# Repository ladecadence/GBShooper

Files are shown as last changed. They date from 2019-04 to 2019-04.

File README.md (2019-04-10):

# GBShooper

Open source hardware GameBoy™ FlashCart Reader/Programmer

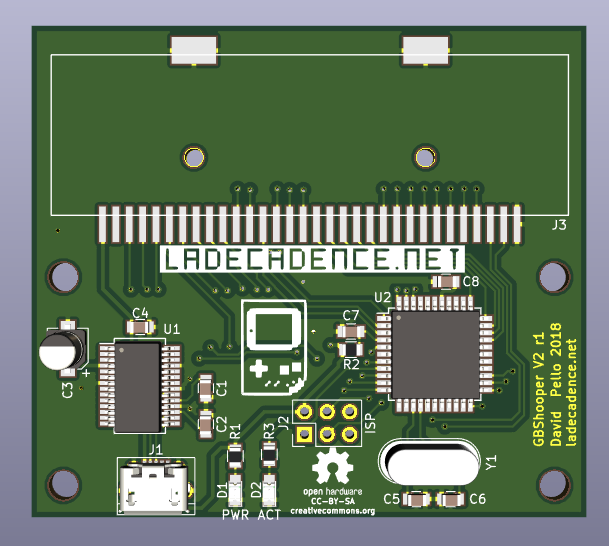
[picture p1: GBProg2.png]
GBShooper PCB


This flashcart programmer, uses the firmware at (https://github.com/ladecadence/GBShooper-Firmware)

For building it, you'll need an Atmega8515L-16AI (TQFP, -8AI also ok), a ft232rl (soic28), a 6MHz xtal, and some passives, like capacitors, resistors and LEDs.

Full Bill of Materials in the BOM file (LibreOffice and PDF).

You'll also need a micro-usb "B" connector, and a GameBoy Cartridge connector. This version uses SMD replacement connectors for the Nintendo DS, you can find them online in Aliexpress or the like.

You can use this programmer to dump original cartridges, and flash DIY flashcarts and some other flashcarts based on DIY designs and nintendo mappers (or clones).
PC-Side software is being developed right now and will also be published at ladecadence.net github.

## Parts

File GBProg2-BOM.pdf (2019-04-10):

GBProg2

Página 1

Id Identificador | Empaquetado | Cantidad Identificación | Suministrador y ref
1 J3 | GB-Cart-NDS-Aliexpress | 1 GB-CART
2 J2 | Pin_Header_Straight_2x03_Pitch2.54mm | 1 ISP
3 J1 | USB_Micro-B | 1 USB_OTG
4 Y1 | Crystal_HC49-4H_Vertical | 1 3.6864MHz
5 C1,C4,C7,C8,C2 | C_0805 | 5 100n
6 C5,C6 | C_0805 | 2 22p
7 D1 | LED_0805 | 1 PWR | Green
8 D2 | LED_0805 | 1 ACT | Red
9 R1,R3 | R_0805 | 2 220
10 R2 | R_0805 | 1 10K
11 U2 | TQFP-44_10x10mm_Pitch0.8mm | 1 ATMEGA8515-16AU | -8AU Also OK
12 C3 | CP_Elec_4x5.3 | 1 4,7u
13 U1 | SSOP-28_5.3x10.2mm_Pitch0.65mm | 1 FT232R

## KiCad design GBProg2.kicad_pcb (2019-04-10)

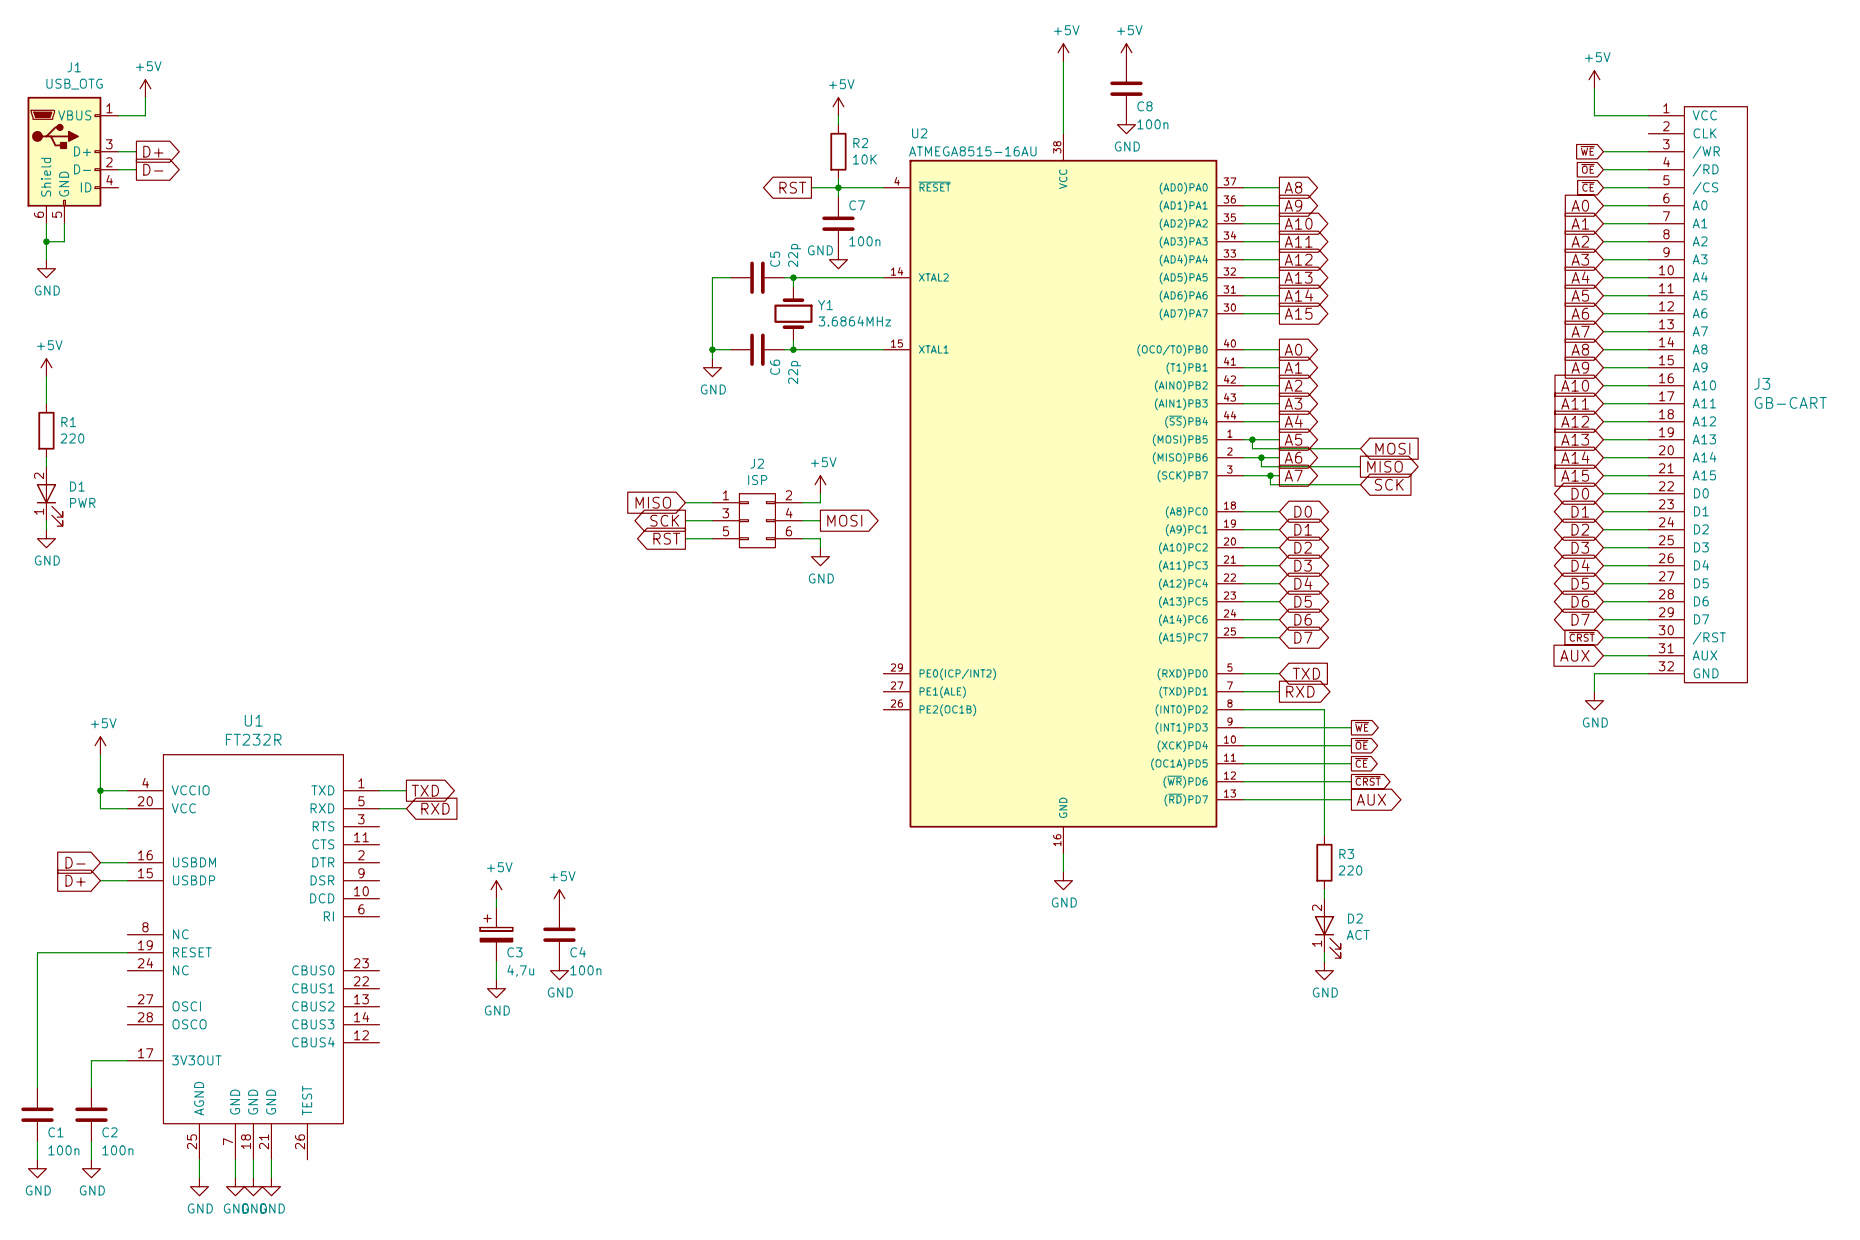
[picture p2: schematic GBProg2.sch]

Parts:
C1, C2, C4, C7, C8: 100n; C_0805
C3: 4,7u; CP_Elec_4x5.3
C5, C6: 22p; C_0805
D1: PWR; LED_0805
D2: ACT; LED_0805
J1: USB_OTG; USB_Micro-B
J2: ISP; Pin_Header_Straight_2x03_Pitch2.54mm
J3: GB-CART; GB-Cart-NDS-Aliexpress
R1, R3: 220; R_0805
R2: 10K; R_0805
U1: FT232R; SSOP-28_5.3x10.2mm_Pitch0.65mm
U2: ATMEGA8515-16AU; TQFP-44_10x10mm_Pitch0.8mm
Y1: 3.6864MHz; Crystal_HC49-4H_Vertical

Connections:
+5V: C3.1, C4.1, C8.1, J1.1 (VBUS), J2.2, J3.1 (VCC), R1.1, R2.1, U1.4 (VCCIO), U1.20 (VCC), U2.38 (VCC)
A0: J3.6 (A0), U2.40 ((OC0/T0)PB0)
A1: J3.7 (A1), U2.41 ((T1)PB1)
A2: J3.8 (A2), U2.42 ((AIN0)PB2)
A3: J3.9 (A3), U2.43 ((AIN1)PB3)
A4: J3.10 (A4), U2.44 ((~SS~)PB4)
A5: J2.4, J3.11 (A5), U2.1 ((MOSI)PB5)
A6: J2.1, J3.12 (A6), U2.2 ((MISO)PB6)
A7: J2.3, J3.13 (A7), U2.3 ((SCK)PB7)
A8: J3.14 (A8), U2.37 ((AD0)PA0)
A9: J3.15 (A9), U2.36 ((AD1)PA1)
A10: J3.16 (A10), U2.35 ((AD2)PA2)
A11: J3.17 (A11), U2.34 ((AD3)PA3)
A12: J3.18 (A12), U2.33 ((AD4)PA4)
A13: J3.19 (A13), U2.32 ((AD5)PA5)
A14: J3.20 (A14), U2.31 ((AD6)PA6)
A15: J3.21 (A15), U2.30 ((AD7)PA7)
AUX: J3.31 (AUX), U2.13 ((~RD~)PD7)
D0: J3.22 (D0), U2.18 ((A8)PC0)
D1: J3.23 (D1), U2.19 ((A9)PC1)
D2: J3.24 (D2), U2.20 ((A10)PC2)
D3: J3.25 (D3), U2.21 ((A11)PC3)
D4: J3.26 (D4), U2.22 ((A12)PC4)
D5: J3.27 (D5), U2.23 ((A13)PC5)
D6: J3.28 (D6), U2.24 ((A14)PC6)
D7: J3.29 (D7), U2.25 ((A15)PC7)
D+: J1.3 (D+), U1.15 (USBDP)
D-: J1.2 (D-), U1.16 (USBDM)
GND: C1.2, C2.2, C3.2, C4.2, C5.1, C6.1, C7.2, C8.2, D1.1 (K), D2.1 (K), J1.5 (GND), J1.6 (Shield), J2.6, J3.32 (GND), U1.7 (GND), U1.18 (GND), U1.21 (GND), U1.25 (AGND), U2.16 (GND)
unnamed: C1.1, U1.19 (RESET)
unnamed: C2.1, U1.17 (3V3OUT)
unnamed: C5.2, U2.14 (XTAL2), Y1.1
unnamed: C6.2, U2.15 (XTAL1), Y1.2
unnamed: D1.2 (A), R1.2
unnamed: D2.2 (A), R3.2
unnamed: R3.1, U2.8 ((INT0)PD2)
RST: C7.1, J2.5, R2.2, U2.4 (~RESET)
RXD: U1.5 (RXD), U2.7 ((TXD)PD1)
TXD: U1.1 (TXD), U2.5 ((RXD)PD0)
~CE: J3.5 (/CS), U2.11 ((OC1A)PD5)
~CRST: J3.30 (/RST), U2.12 ((~WR~)PD6)
~OE: J3.4 (/RD), U2.10 ((XCK)PD4)
~WE: J3.3 (/WR), U2.9 ((INT1)PD3)

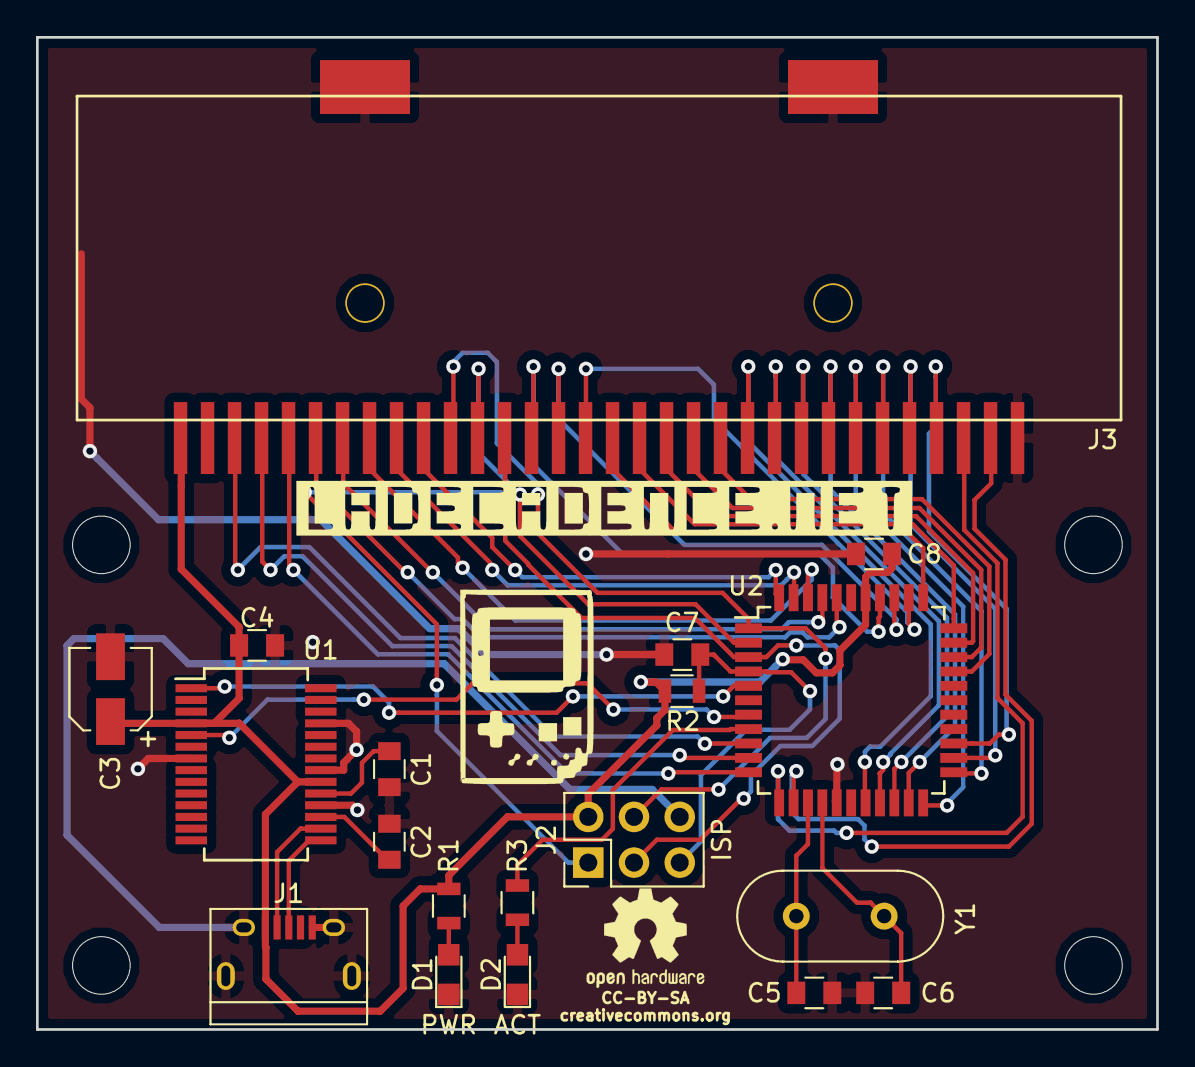
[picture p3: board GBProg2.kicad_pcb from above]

Board: 2 copper layers, 62.2 x 55.1 mm, 19 parts (0 on the bottom side), 43 nets.

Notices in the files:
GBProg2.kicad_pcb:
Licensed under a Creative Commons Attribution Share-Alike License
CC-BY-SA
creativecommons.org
